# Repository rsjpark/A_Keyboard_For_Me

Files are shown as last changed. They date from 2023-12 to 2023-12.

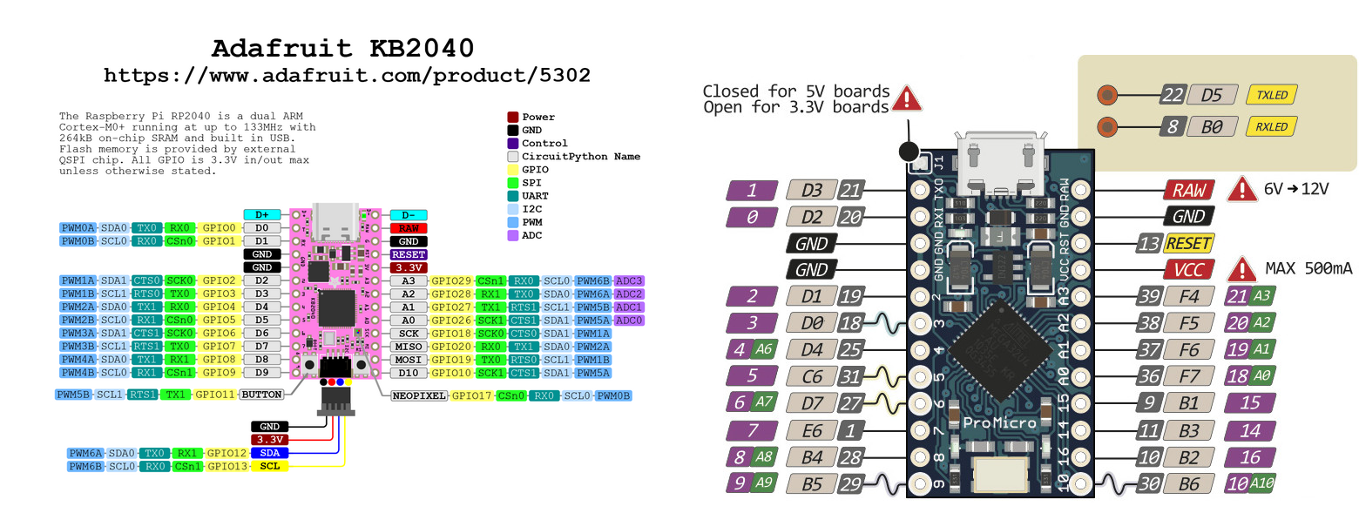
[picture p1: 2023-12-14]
slide images/0.2_pinout_comparison.png

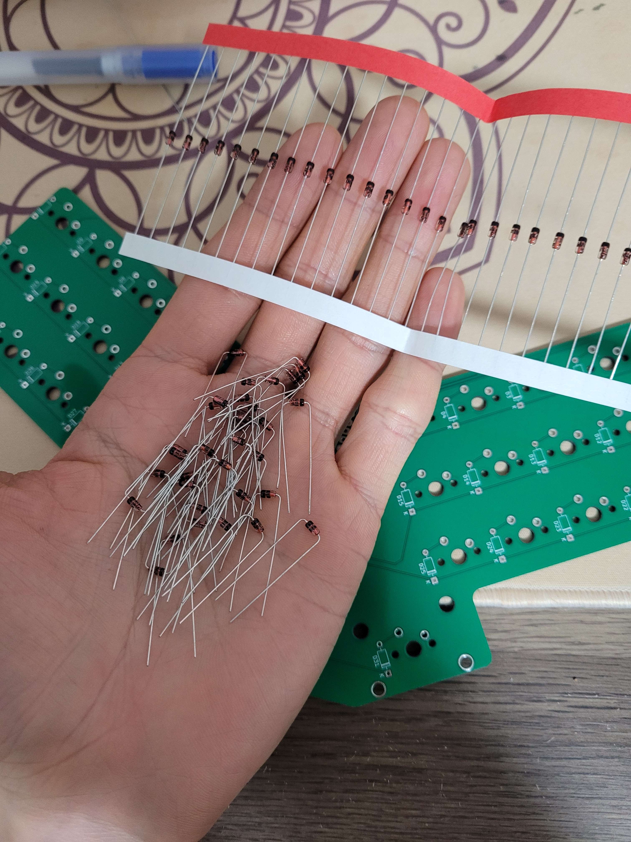
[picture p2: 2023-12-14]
slide images/007.jpg

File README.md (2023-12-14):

# A_Keyboard_For_Me
CISC 4900 RPark

# Goals
A Keyboard For Me was designed to create a common tool from the ground up to customize the ergonomics and to be a learning experience

# Process
What we can design and have manufactured ourselves reasonably are the case, pcb, and plate. Other miscellaneous parts will be bought or are already in possession.

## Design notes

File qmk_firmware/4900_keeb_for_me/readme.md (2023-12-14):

# A Keyboard For Me is a project designed to learn about the processes of making/designing a keyboard from the ground up in order to build a tool that is fully customized for me

# It allows me to tailor the shape of the keyboard for ergonomics as well as the firmware for workflow efficiency and ergonomics (having every key be near home row and not having to reach out more than 2 keys)

# I will tackle the challenges of designing/creating a case, pcb, plate, and firmware. Parts such as stabilizers, switches, keycaps, and other mechanical parts will be bought.

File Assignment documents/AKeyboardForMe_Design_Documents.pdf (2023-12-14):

A Keyboard For Me

Richard Park:
rsjpark2@gmail.com
richard.park24@bcmail.cuny.edu

The A Keyboard For Me aims to build a fully customized and functional keyboard from the ground up. It will begin by reexamining the archetypal keyboard to best fit my needs. It will look to first determine my personal preferences and then to build the case, pcb, plate, and firmware around that crucial factor. The hardware specifications will be determined by the ergonomic choices, and the firmware will be determined by my desired keymapping and preferred workflow.

Exact schedule is yet to be determined but I will be updating the trello often, and I plan on ordering manufacturing parts by mid/late October.

This is the todo trello board as of now, and they will be mapped to the schedule board later this week

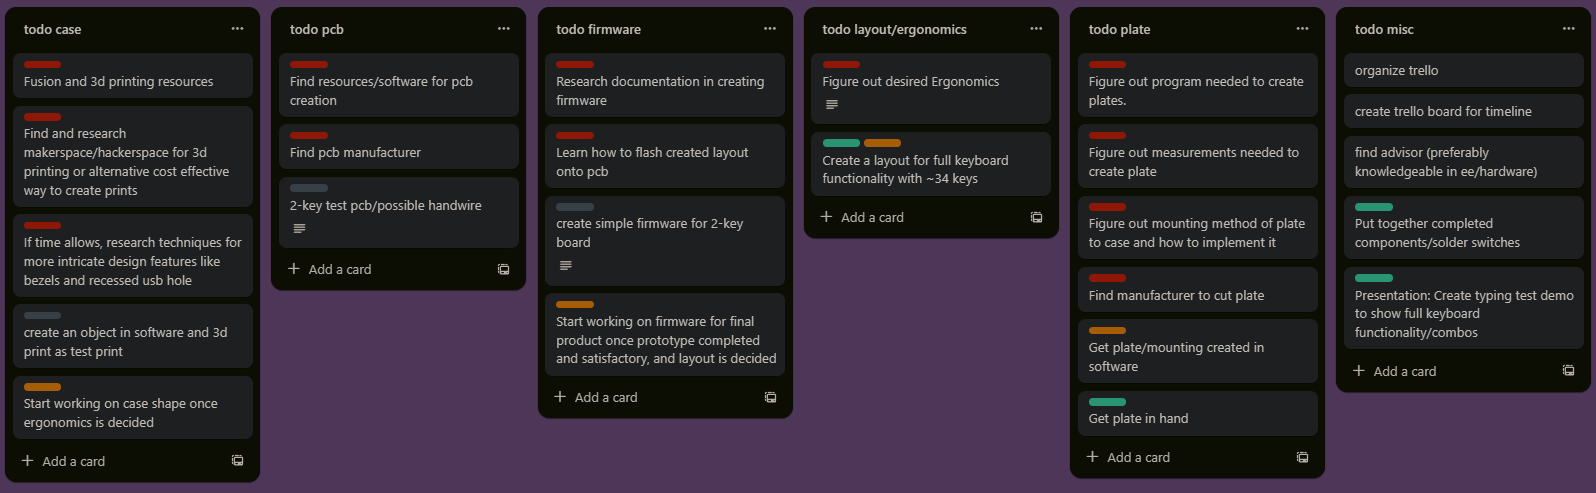
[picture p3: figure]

This opportunity to explore hardware and manufacturing offers me a stepping stone into further ventures for building tools/machines from the ground up. I would like to explore more with 3d printing and machining, working with circuit boards and electronics, and taking a deeper dive into programming and utilizing microcontrollers. This project offers a unique opportunity to explore all of those realms at once while also ending up with a fully tailored and functional end product.

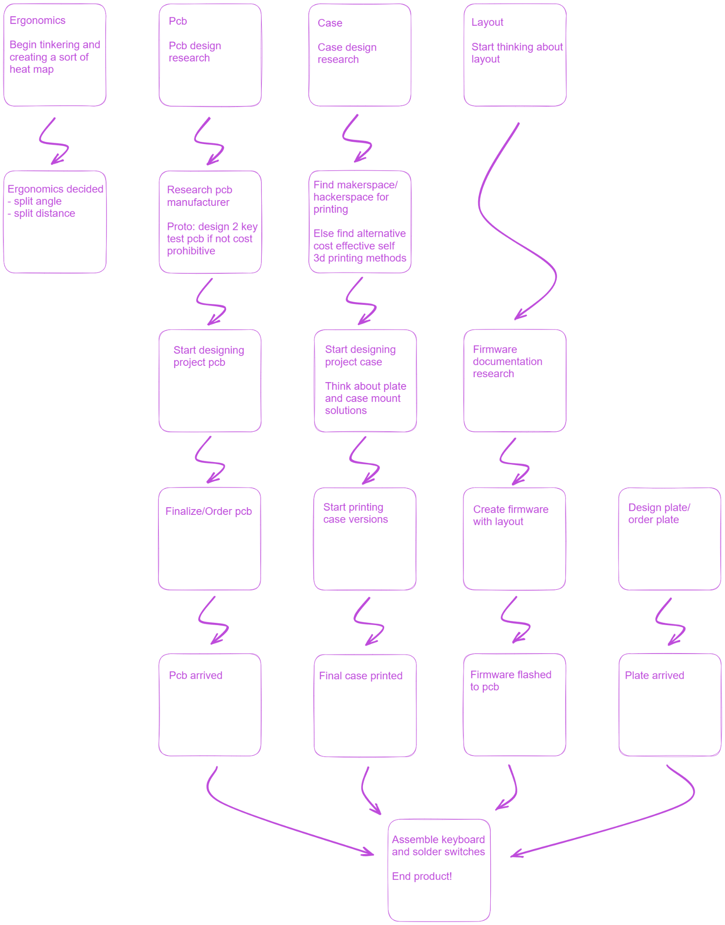
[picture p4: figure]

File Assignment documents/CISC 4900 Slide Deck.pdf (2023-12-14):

# A Keyboard For Me

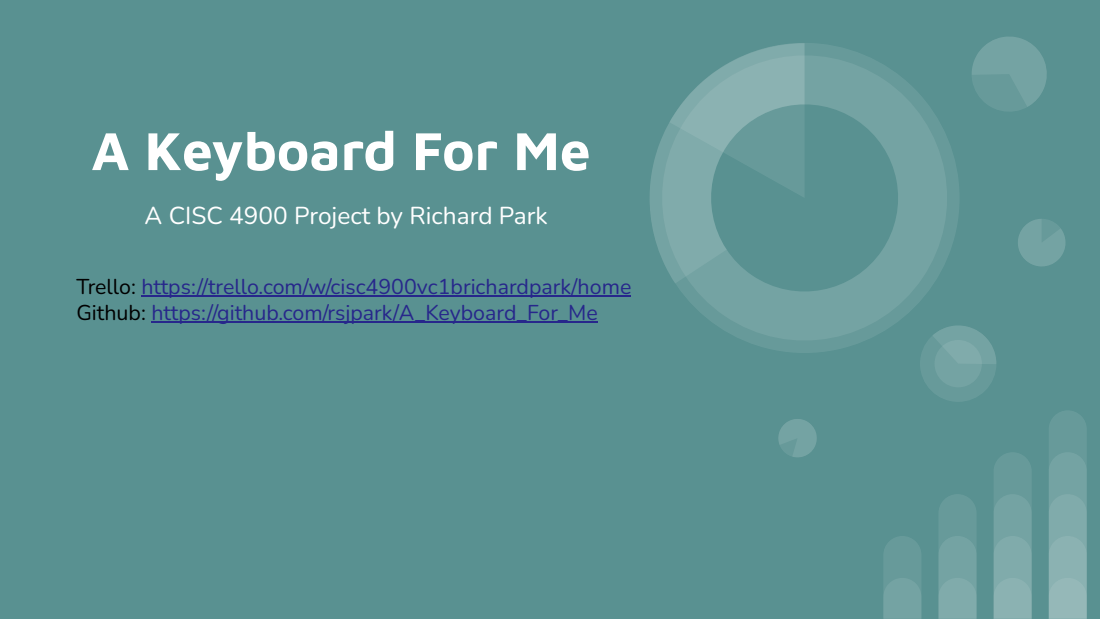
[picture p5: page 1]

A CISC 4900 Project by Richard Park

Trello: https://trello.com/w/cisc4900vc1brichardpark/home
Github: https://github.com/rsjpark/A_Keyboard_For_Me

# Case Design

Original Plans
- I had wanted to do a simple no frills case, that would be simple to print/manufacture and wouldn’t take up a bulk of my time.
Demo 1 Timeline
- Many of my hours were spent trying to get measurements for all of the aspects of the case, especially ones that I had not originally thought about.
- At the moment I have 4 case designs that I’m slightly iterating on, with 2 of them being one that I feel will make the final cut.
- I am still figuring out final decisions, as I hadn’t thought of specifics like, where the mounting holes should be since this case won’t be a single rectangle.
- I am hoping for a minimal amount of mounting holes so I will continue to iterate

# Case Design (cont.)

After Demo 1 Timeline

- After all of those designs, I had to scrap them due to pcb issues
- Having to accommodate the development board rather than just the mcu meant that I would have to change up dimensions

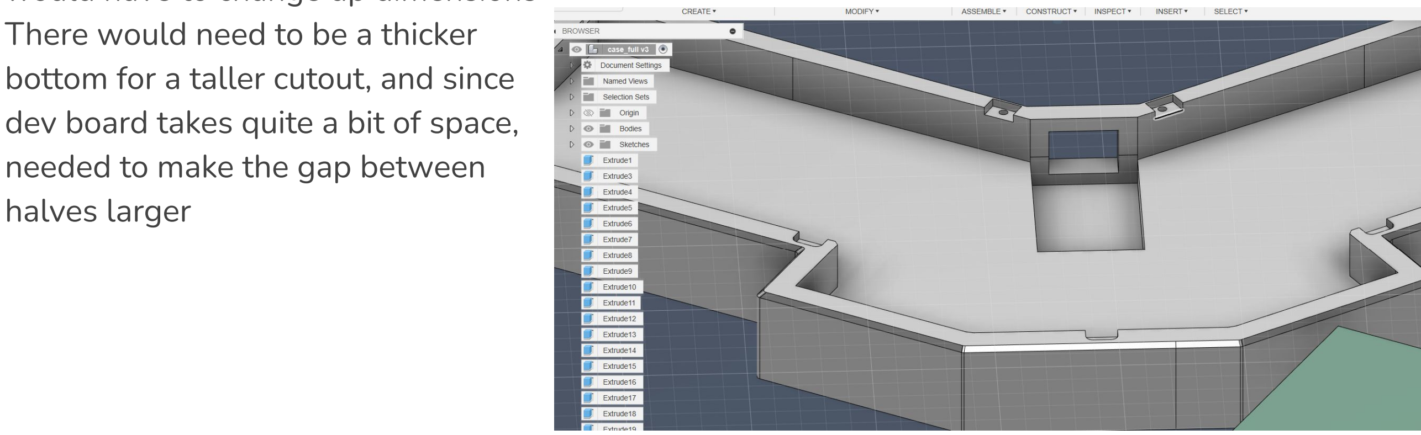
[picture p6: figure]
dev board takes quite a bit of space,; needed to make the gap between halves larger

- There would need to be a thicker
bottom for a taller cutout, and since | the

# Case Design (cont.)

After Demo 1 Timeline

- I decided to wait until my pcb was finalized and until I could get all of the dimensions (pcb, plate, development board, pin headers)
- This step took quite a while

# Case Design (cont.)

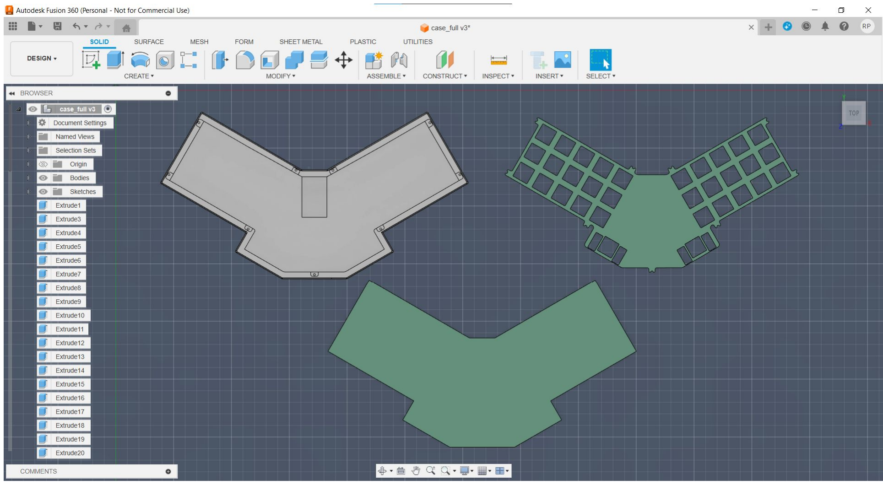
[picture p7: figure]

After Demo 1 Timeline

- The dimensions were given by creating an object in kicad that traced the dimensions of the plate and then imported as a step file into fusion
- After some hard fought tinkering the case came into its own

# Case Manufacturing

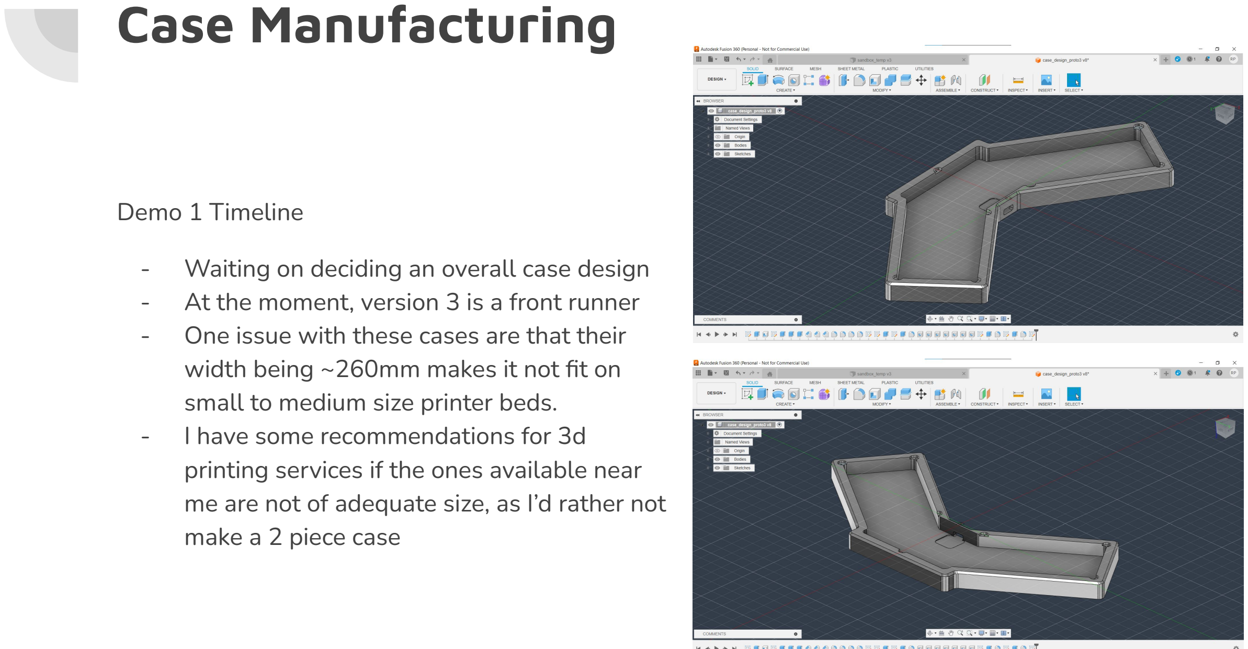
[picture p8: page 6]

Demo 1 Timeline

- Waiting on deciding an overall case design
- At the moment, version 3 is a front runner
- One issue with these cases are that their width being ~260mm makes it not fit on small to medium size printer beds.
- I have some recommendations for 3d printing services if the ones available near me are not of adequate size, as I’d rather not make a 2 piece case

# Case Manufacturing (cont.)

After Demo 1 Timeline

- I had originally planned to go to the Queens Library in Queensbridge to attempt to print the case, but was not able to due to availability.
- I chose to just make another order through jlc and sent in my files for printing
- Although I had created with tolerances in mind, the prints were very good, and made the 1mm edge tolerance I measured with look like the Grand Canyon when the plate was screwed in

# Case Manufacturing (cont.)

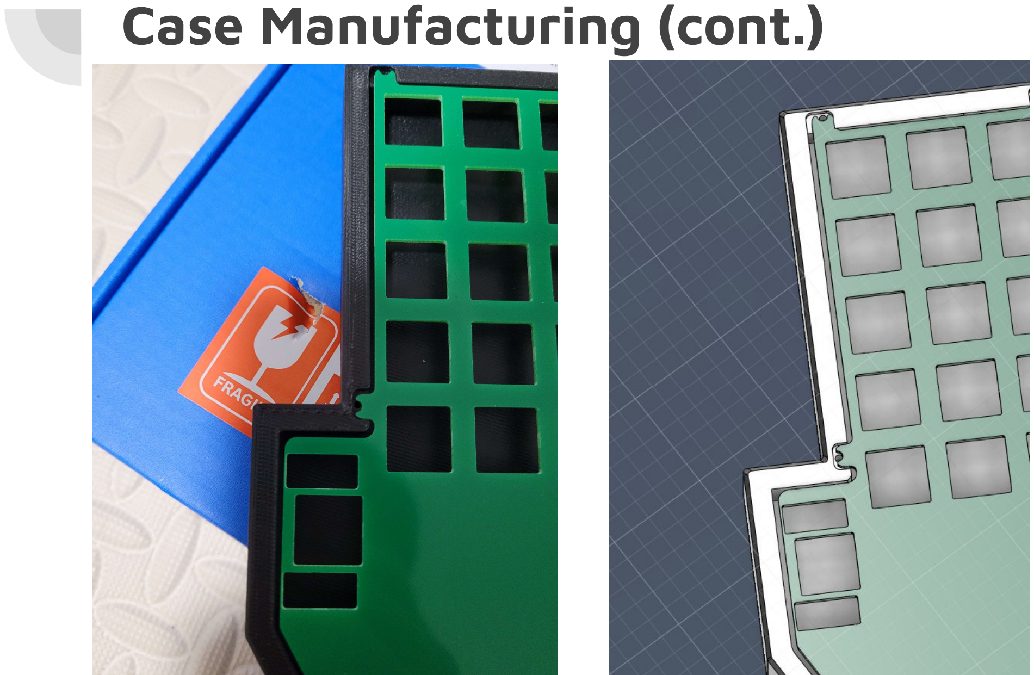
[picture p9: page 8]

# PCB Design

Original Plans

- Create an integrated pcb (simple as that)

Demo 1 Timeline

- As presented in the demo, I had finished up the pcb with rp2040/kb2040 devboard.
- As I wait on production, I am working on a whole new revision that is an integrated pcb

# PCB Design (cont.)

After Demo 1 Timeline
- My original plan was to go and order the pcb I had by Demo 1 as the safety/working exercise pcb.
- …I couldn’t send it in for production. It was too messy
- I decided to just start working on the integrated pcb and have that ordered within a few weeks.
- It turned out to be too hard of a task. I was reading documentation on all of the extra parts needed that was already included in the development board.
- I was working on learning up on crystals/oscillators that were necessary due to the usb’s strict protocols on timing, but realized I was running out of time.

# PCB Design (cont.)

After Demo 1 Timeline

- I decided that with the new stuff that I learned along the way, I needed to get the kb2040 pcb redone and out for production.
- This still took around 2 weeks as I was still having troubles with routing and trying to troubleshoot the errors showing up in the drc
- Eventually with trial and error of redefining the pins on the dev board I was able to get it to a place where I could send it in for production

# PCB Design (cont.)

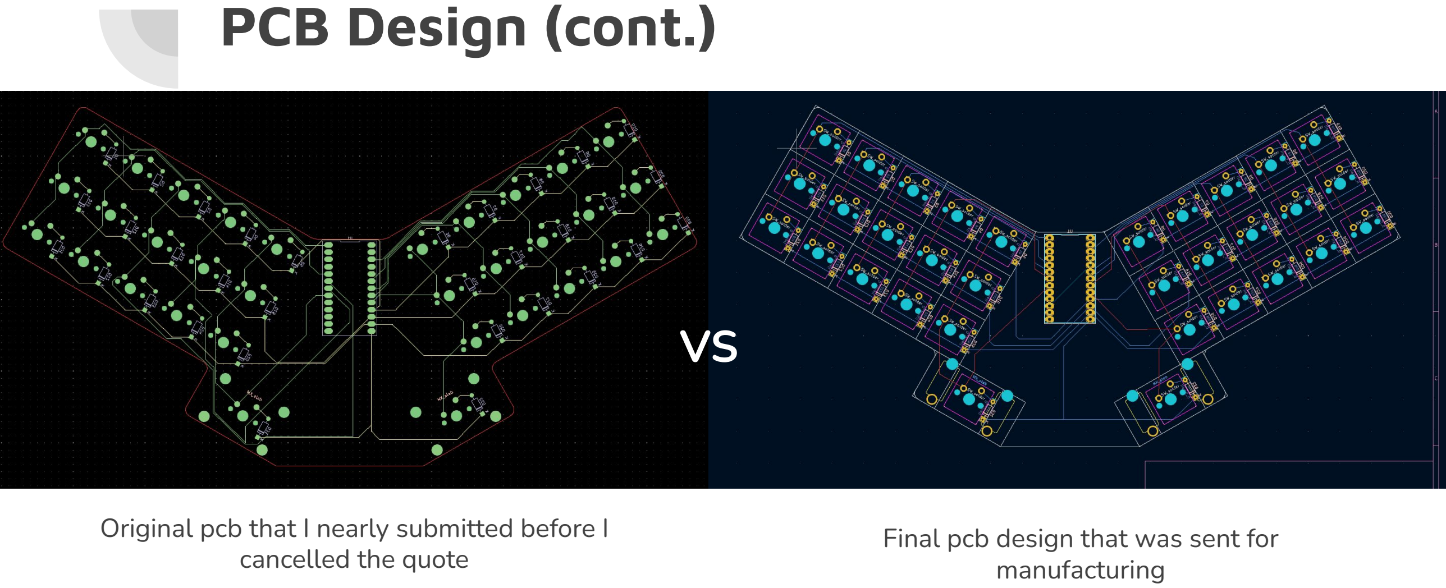
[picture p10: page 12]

VS

Original pcb that I nearly submitted before I cancelled the quote

Final pcb design that was sent for manufacturing

# PCB Manufacturing

Demo 1 Timeline

- Currently I have the devkit version of the pcb going through a manual quote because the autoquoter was having issues. I hope to hear back from them in a few days.
- While that pcb is being quoted and sent for production, I will be continuing on working on the integrated pcb, making the devkit pcb a backup in case something goes wrong or I don’t have enough time.
- Side note for the case, I saw that jlc has 3d printing and material milling services as well, so if all goes well and the price is reasonable I might check out their options.
- Milled polycarbonate or abs seems like a very interesting option

# PCB Manufacturing (cont.)

After Demo 1 Timeline
- The ordering process came with its own hiccups.
- Many of the scripts that were used to create a BOM and the centroid

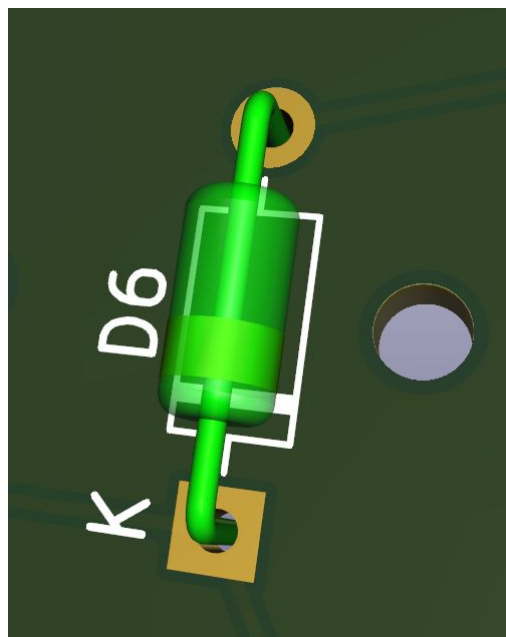
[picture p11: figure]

files for jlc were not working and it took a bit of work to troubleshoot the errors
- Those files were eventually created and sent for quoting, and in | a
few days I received a notice from jlc that there was an issue with
my order in which I had chosen parts (surface mount diode) that | did
not work with the footprint that I had placed on my pcb
(through holes for tht diodes)...

# PCB Manufacturing (cont.)

After Demo 1 Timeline

- After some back and forth emails, I had decided that it would be easier to order and solder the diodes myself, rather than replace the footprints due to the rotation/positioning of my footprints
- They cancelled the assembly and proceeded with the order (which also had the plate in it)
- After receiving the parts in hand, everything looked great, which was a relief since their integrated gerber viewer was showing some wonky things

# PCB Manufacturing (cont.)

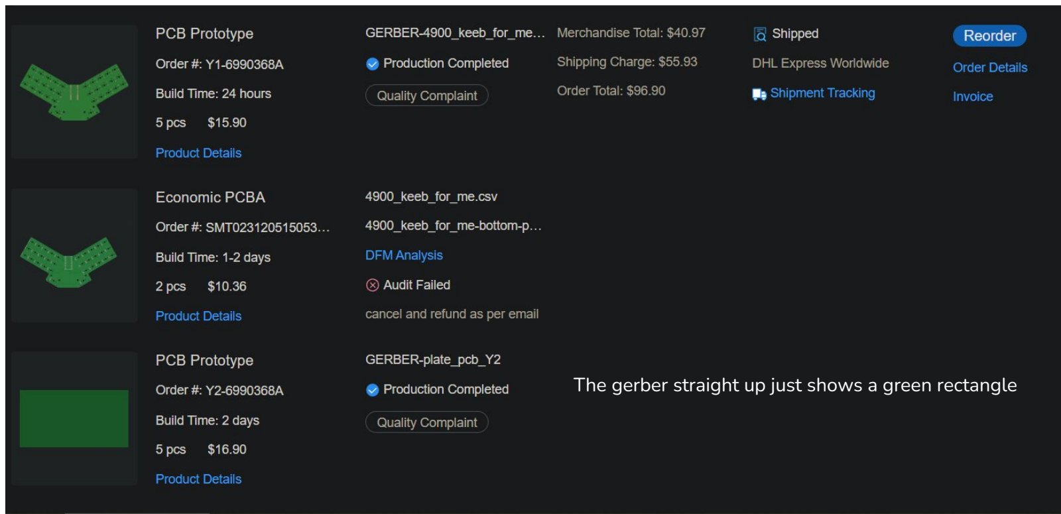
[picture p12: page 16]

The gerber straight up just shows a green rectangle

# Plate Design

Original Plans

- Create plates based off of pcb and case designs
- Create them while waiting for pcb manufacturing and case prototyping

Demo 1 Timeline

- Not much has changed
- Design follows the case design, so once the mounting worries are sorted out, should be easy enough to create a plate

# Plate Design (cont.)

After Demo 1 Timeline

- The plate design portion was rather simple, and just took a few hours of playing around with the pcb kicad files and some lines/filleting
- I was able to use the dimensions of the plate to base my case dimensions off of as mentioned before

# Plate Design (cont.)

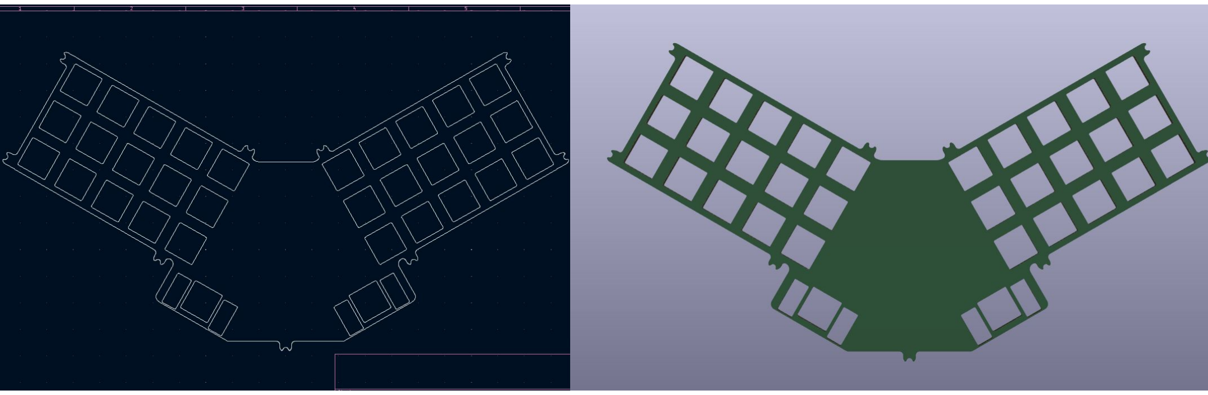
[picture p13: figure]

# Plate Manufacturing

Demo 1 Timeline

- Waiting on final case design
- Still the same plans as talked about in the demo

# Plate Manufacturing (cont.)

After Demo 1 Timeline

- Sent in files for manufacturing along with pcb
- Nothing went wrong in this department

# Plate Manufacturing (cont.)

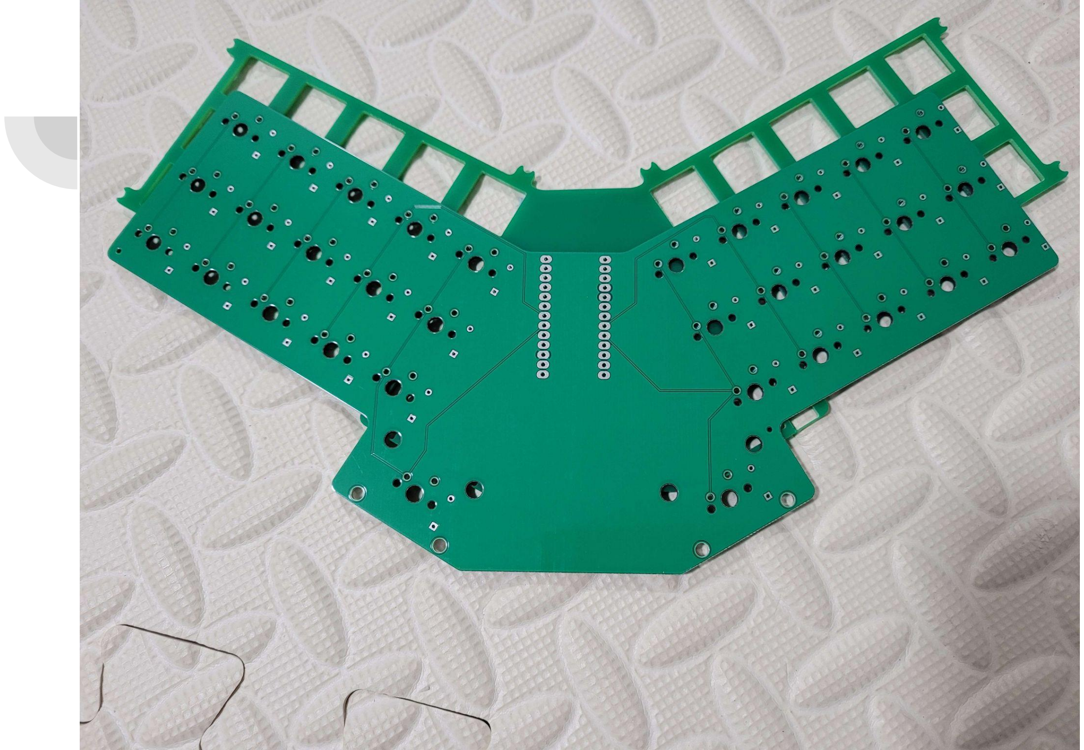
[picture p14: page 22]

# Layout Creation

Demo 1 Timeline

- Layout has been finalized
- Layers have been organized in google sheets so that it won’t be a headache when creating a firmware for it

# Firmware creation

Demo 1 Timeline

- Have not started working on firmware

# Firmware creation (cont.)

After Demo 1 Timeline
- Firmware creation was pretty straightforward
- Reading the QMK documentation and looking at examples of other qmk keyboard firmwares made it pretty clear what I needed/wanted
- After I implemented my layout I had some errors in compiling my firmware with qmk msys and chalked it up to some mistakes and decided to chip at it over time.
- After some time I realized that nothing I was trying was working, and after some research and asking around I realized that in order to create your own keyboard/firmware and get it compiled in qmk you need to submit a pull request towards the main branch and get it accepted

# Firmware creation (cont.)

After Demo 1 Timeline

- This was an issue as I thought that the firmware side of things was pretty much nearly done
- I did more digging and found 2 possible solutions.
- Compile the firmware with the pico-sdk rather than qmk
- Try out a hack where you use an already accepted keyboard’s files and insert your own and try to compile it
- At this point I didn’t have enough time to learn building firmware that wasn’t from QMK, and my jlc orders were still not in hand
- I decided to go through the list of keyboards in the list until I found a keyboard that was similar to mine and decided insert my files and compile my firmware as if it was that keyboard
- I chose the reviung39 because it looked similar to my board, but it turned out that they were created very differently.
- There was quite a bit of troubleshooting that took a few weeks, but I eventually was able to compile my firmware and got the uf2 file that I needed to flash my rp2040/kb2040

# Assembly

- This was when I started testing my board since I had put the firmware into the kb2040 already in advance.
- It was not pretty. The keytester was showing up random keys and mostly no keypresses.
- After some troubleshooting I decided to just solder in the switches and try to get a complete look of the build.
- The screws threaded themselves well and at least the physical build was complete. Although I am looking to sand the usb port down a few mm
- I took out the pcb from the case and have been troubleshooting since.
- I was able to get to this point where many of the keys are still not registering correctly.
- I am trying to work until the very end, but cannot determine where the issues lie. I’m wondering if it’s a combination of both issues in the firmware and hardware/assembly.

# Assembly

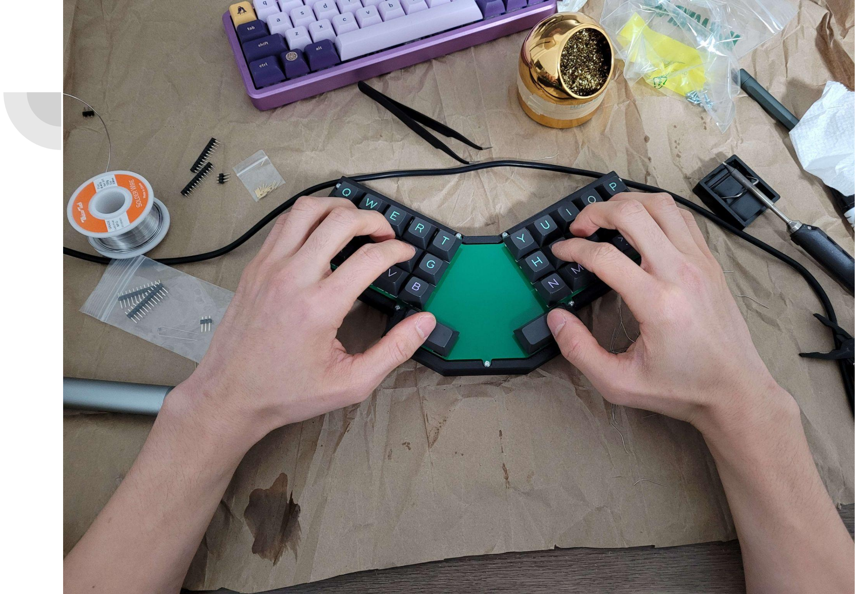
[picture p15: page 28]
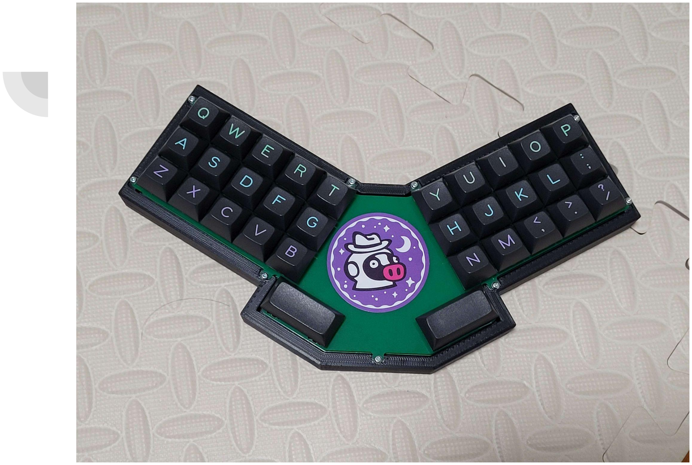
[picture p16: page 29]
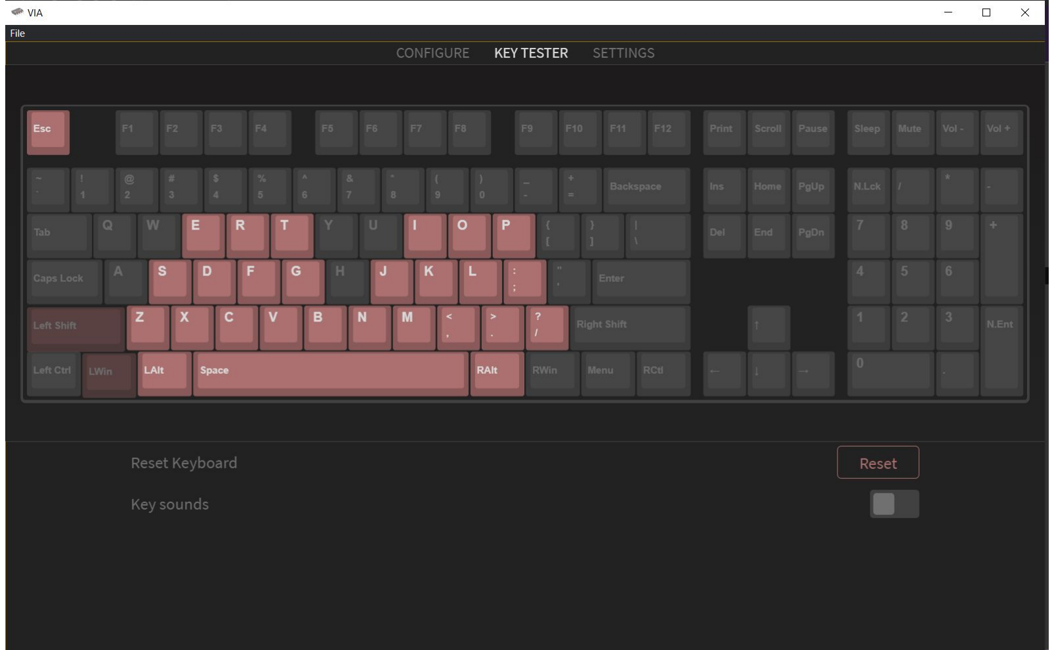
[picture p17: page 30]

# Final Thoughts

- In the end I do not have a fully functional working product
- I feel like I’m very close and will continue working this out until I have a fully functional build,
- This project was a great experience in all of the issues that could arise when I create my next design.
- I think finishing this out will give me even better insight that I can carry along with me.
- Although this was very stressful (lol) I am very happy to have dove into the deep end to get me rolling on electrical components and 3d modeling.
- I retrospect, I think treating this project as both a learning/getting experience, as well as trying to fulfill a goal of satisfying my ergonomic needs was way too much.
- I believe starting out with a smaller perhaps 4-key test board, finalizing it, then moving onto a slightly more complicated, but still normal board would have really made things fall better into schedule.

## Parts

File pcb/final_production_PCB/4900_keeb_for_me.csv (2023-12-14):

Comment | Designator | Footprint | LCSC Part #
1N4148 | D1,D2,D3,D4,D5,D6,D7,D8,D9,D10,D11,D12,D13,D14,D15,D16,D17,D18,D19,D20,D21,D22,D23,D24,D25,D26,D27,D28,D29,D30,D31,D32,U1 | Diode_THT:D_DO-35_SOD27_P7.62mm_Horizontal

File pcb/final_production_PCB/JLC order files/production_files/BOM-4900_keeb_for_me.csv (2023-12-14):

Comment | Designator | Footprint | LCSC
MX_SW_solder | SW3 | SW_MX_1u
MX_SW_solder | SW21 | SW_MX_1u
MX_SW_solder | SW22 | SW_MX_1u
MX_SW_solder | SW17 | SW_MX_1u
MX_SW_solder | SW27 | SW_MX_1u
MX_SW_solder | SW15 | SW_MX_1u
MX_SW_solder | SW29 | SW_MX_1u
MX_SW_solder | SW1 | SW_MX_1u
MX_SW_solder | SW12 | SW_MX_1u
MX_SW_solder | SW13 | SW_MX_1u
MX_SW_solder | SW6 | SW_MX_1u
MX_SW_solder | SW28 | SW_MX_1u
MX_SW_solder | SW9 | SW_MX_1u
MX_SW_solder | SW19 | SW_MX_1u
MX_SW_solder | SW20 | SW_MX_1u
MX_stab | S32 | STAB_MX_P_2u
MX_SW_solder | SW31 | SW_MX_1u
MX_SW_solder | SW7 | SW_MX_1u
MX_SW_solder | SW4 | SW_MX_1u
MX_SW_solder | SW5 | SW_MX_1u
MX_SW_solder | SW18 | SW_MX_1u
MX_SW_solder | SW11 | SW_MX_1u
MX_SW_solder | SW2 | SW_MX_1u
MX_SW_solder | SW23 | SW_MX_1u
MX_SW_solder | SW14 | SW_MX_1u
MX_SW_solder | SW24 | SW_MX_1u
MX_stab | S31 | STAB_MX_P_2u
MX_SW_solder | SW25 | SW_MX_1u
MX_SW_solder | SW8 | SW_MX_1u
MX_SW_solder | SW16 | SW_MX_1u
MX_SW_solder | SW32 | SW_MX_1u
MX_SW_solder | SW10 | SW_MX_1u
MX_SW_solder | SW30 | SW_MX_1u
MX_SW_solder | SW26 | SW_MX_1u
D_Small | D21 | D_DO-35_SOD27_P7.62mm_Horizontal
D_Small | D16 | D_DO-35_SOD27_P7.62mm_Horizontal
D_Small | D7 | D_DO-35_SOD27_P7.62mm_Horizontal
D_Small | D11 | D_DO-35_SOD27_P7.62mm_Horizontal
D_Small | D15 | D_DO-35_SOD27_P7.62mm_Horizontal
D_Small | D18 | D_DO-35_SOD27_P7.62mm_Horizontal
D_Small | D17 | D_DO-35_SOD27_P7.62mm_Horizontal
D_Small | D28 | D_DO-35_SOD27_P7.62mm_Horizontal
D_Small | D2 | D_DO-35_SOD27_P7.62mm_Horizontal
D_Small | D1 | D_DO-35_SOD27_P7.62mm_Horizontal
D_Small | D25 | D_DO-35_SOD27_P7.62mm_Horizontal
D_Small | D19 | D_DO-35_SOD27_P7.62mm_Horizontal
D_Small | D24 | D_DO-35_SOD27_P7.62mm_Horizontal
D_Small | D31 | D_DO-35_SOD27_P7.62mm_Horizontal
D_Small | D22 | D_DO-35_SOD27_P7.62mm_Horizontal
D_Small | D30 | D_DO-35_SOD27_P7.62mm_Horizontal
D_Small | D29 | D_DO-35_SOD27_P7.62mm_Horizontal
D_Small | D3 | D_DO-35_SOD27_P7.62mm_Horizontal
~ | U1 | Pro-Micro
D_Small | D5 | D_DO-35_SOD27_P7.62mm_Horizontal
D_Small | D27 | D_DO-35_SOD27_P7.62mm_Horizontal
D_Small | D13 | D_DO-35_SOD27_P7.62mm_Horizontal
D_Small | D23 | D_DO-35_SOD27_P7.62mm_Horizontal
D_Small | D26 | D_DO-35_SOD27_P7.62mm_Horizontal
D_Small | D20 | D_DO-35_SOD27_P7.62mm_Horizontal
D_Small | D14 | D_DO-35_SOD27_P7.62mm_Horizontal
D_Small | D8 | D_DO-35_SOD27_P7.62mm_Horizontal
D_Small | D6 | D_DO-35_SOD27_P7.62mm_Horizontal
D_Small | D10 | D_DO-35_SOD27_P7.62mm_Horizontal
D_Small | D4 | D_DO-35_SOD27_P7.62mm_Horizontal
D_Small | D32 | D_DO-35_SOD27_P7.62mm_Horizontal
D_Small | D9 | D_DO-35_SOD27_P7.62mm_Horizontal
D_Small | D12 | D_DO-35_SOD27_P7.62mm_Horizontal

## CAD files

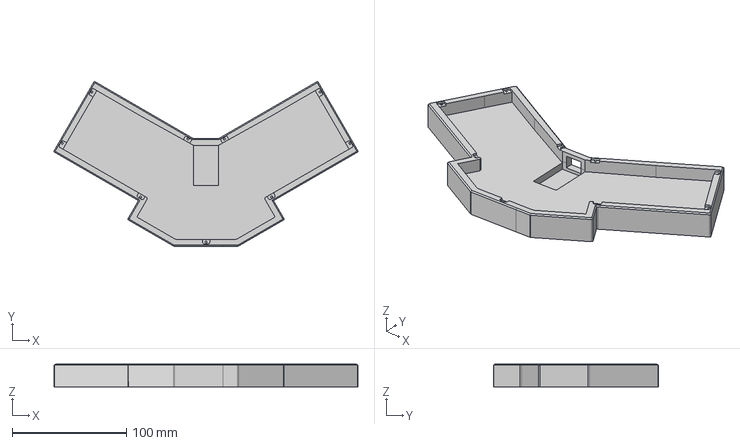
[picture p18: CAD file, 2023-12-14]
case/case_full v3.step
265.9 x 144.1 x 20.0 mm

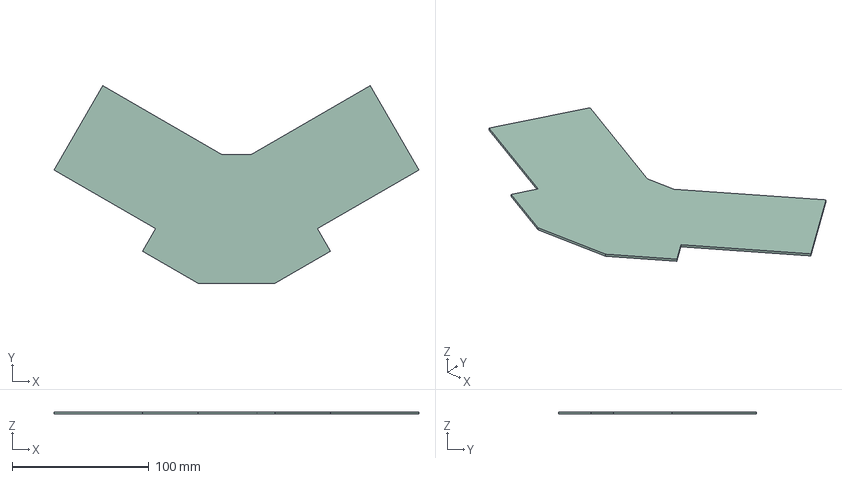
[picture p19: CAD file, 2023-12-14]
case/case_outline.step
266.7 x 144.5 x 1.60 mm

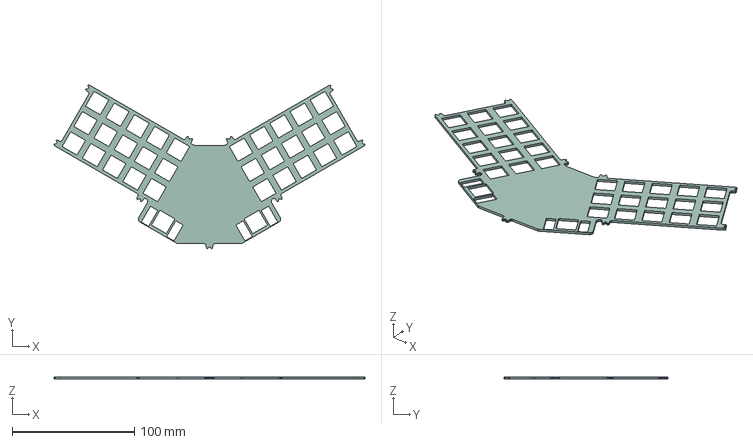
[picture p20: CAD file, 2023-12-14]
case/plate_pcb v1.step
254.0 x 133.7 x 1.60 mm

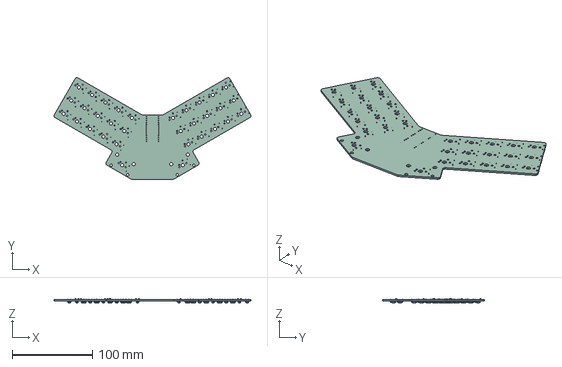
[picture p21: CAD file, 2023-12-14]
case/fixed_pcb.step
245.8 x 127.0 x 5.01 mm
_autosave-4900_keeb_for_me PCB

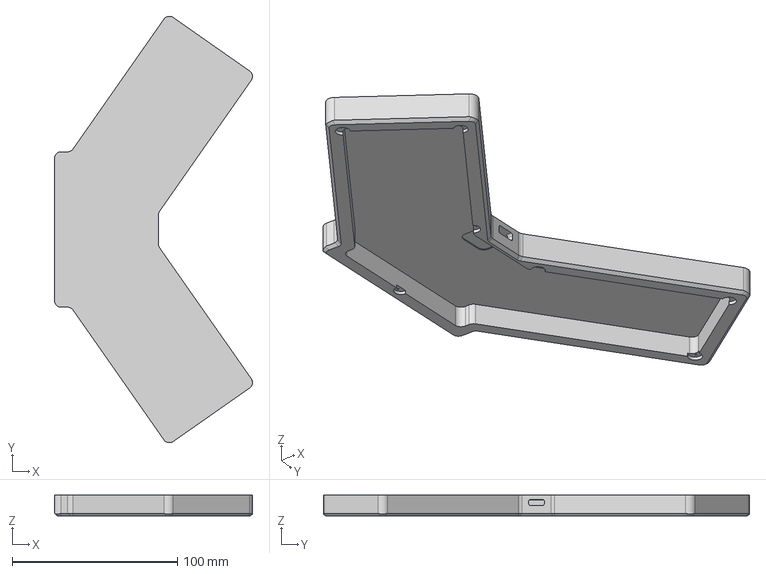
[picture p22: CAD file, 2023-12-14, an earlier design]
case/case_4900_outdated.step
119.8 x 258.0 x 12.5 mm

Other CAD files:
case/fusion_360_crash_course_examples/fillet_chamfer_exercise.f3d
case/fusion_360_crash_course_examples/phone_stand.f3d

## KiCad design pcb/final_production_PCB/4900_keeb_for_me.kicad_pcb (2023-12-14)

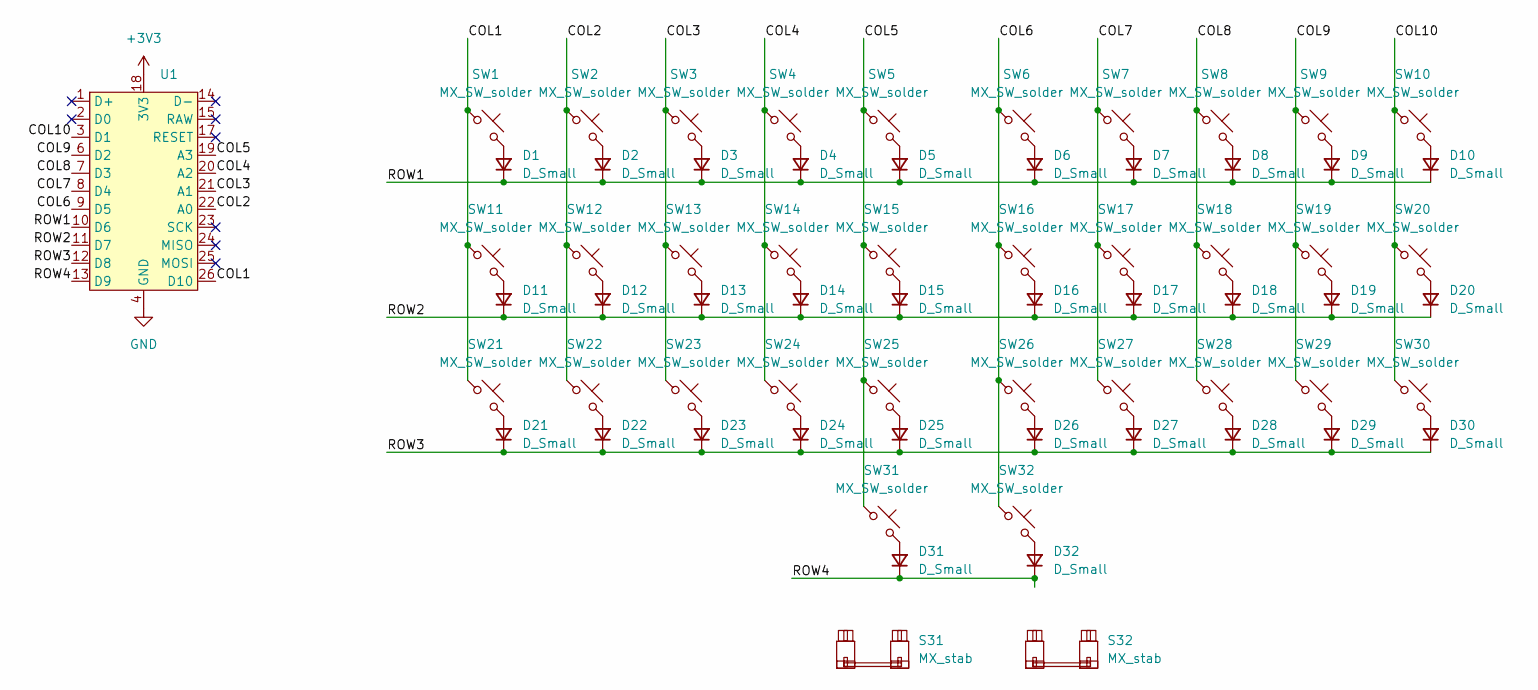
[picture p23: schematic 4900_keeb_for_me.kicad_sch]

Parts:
D1, D2, D3, D4, D5, D6, D7, D8, D9, D10, D11, D12, D13, D14, D15, D16, D17, D18, D19, D20, D21, D22, D23, D24, D25, D26, D27, D28, D29, D30, D31, D32: D_Small; D_DO-35_SOD27_P7.62mm_Horizontal
S31, S32: MX_stab; STAB_MX_P_2u
SW1, SW2, SW3, SW4, SW5, SW6, SW7, SW8, SW9, SW10, SW11, SW12, SW13, SW14, SW15, SW16, SW17, SW18, SW19, SW20, SW21, SW22, SW23, SW24, SW25, SW26, SW27, SW28, SW29, SW30, SW31, SW32: MX_SW_solder; SW_MX_1u
U1: Pro-Micro

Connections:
+3V3: U1.18 (3V3)
/COL1: SW1.1, SW11.1, SW21.1, U1.26 (D10)
/COL2: SW2.1, SW12.1, SW22.1, U1.22 (A0)
/COL3: SW3.1, SW13.1, SW23.1, U1.21 (A1)
/COL4: SW4.1, SW14.1, SW24.1, U1.20 (A2)
/COL5: SW5.1, SW15.1, SW25.1, SW31.1, U1.19 (A3)
/COL6: SW6.1, SW16.1, SW26.1, SW32.1, U1.9 (D5)
/COL7: SW7.1, SW17.1, SW27.1, U1.8 (D4)
/COL8: SW8.1, SW18.1, SW28.1, U1.7 (D3)
/COL9: SW9.1, SW19.1, SW29.1, U1.6 (D2)
/COL10: SW10.1, SW20.1, SW30.1, U1.3 (D1)
/ROW1: D1.1 (K), D2.1 (K), D3.1 (K), D4.1 (K), D5.1 (K), D6.1 (K), D7.1 (K), D8.1 (K), D9.1 (K), D10.1 (K), U1.10 (D6)
/ROW2: D11.1 (K), D12.1 (K), D13.1 (K), D14.1 (K), D15.1 (K), D16.1 (K), D17.1 (K), D18.1 (K), D19.1 (K), D20.1 (K), U1.11 (D7)
/ROW3: D21.1 (K), D22.1 (K), D23.1 (K), D24.1 (K), D25.1 (K), D26.1 (K), D27.1 (K), D28.1 (K), D29.1 (K), D30.1 (K), U1.12 (D8)
/ROW4: D31.1 (K), D32.1 (K), U1.13 (D9)
GND: U1.4 (GND), U1.5 (GND), U1.16 (GND)
unnamed: D1.2 (A), SW1.2
unnamed: D2.2 (A), SW2.2
unnamed: D3.2 (A), SW3.2
unnamed: D4.2 (A), SW4.2
unnamed: D5.2 (A), SW5.2
unnamed: D6.2 (A), SW6.2
unnamed: D7.2 (A), SW7.2
unnamed: D8.2 (A), SW8.2
unnamed: D9.2 (A), SW9.2
unnamed: D10.2 (A), SW10.2
unnamed: D11.2 (A), SW11.2
unnamed: D12.2 (A), SW12.2
unnamed: D13.2 (A), SW13.2
unnamed: D14.2 (A), SW14.2
unnamed: D15.2 (A), SW15.2
unnamed: D16.2 (A), SW16.2
unnamed: D17.2 (A), SW17.2
unnamed: D18.2 (A), SW18.2
unnamed: D19.2 (A), SW19.2
unnamed: D20.2 (A), SW20.2
unnamed: D21.2 (A), SW21.2
unnamed: D22.2 (A), SW22.2
unnamed: D23.2 (A), SW23.2
unnamed: D24.2 (A), SW24.2
unnamed: D25.2 (A), SW25.2
unnamed: D26.2 (A), SW26.2
unnamed: D27.2 (A), SW27.2
unnamed: D28.2 (A), SW28.2
unnamed: D29.2 (A), SW29.2
unnamed: D30.2 (A), SW30.2
unnamed: D31.2 (A), SW31.2
unnamed: D32.2 (A), SW32.2

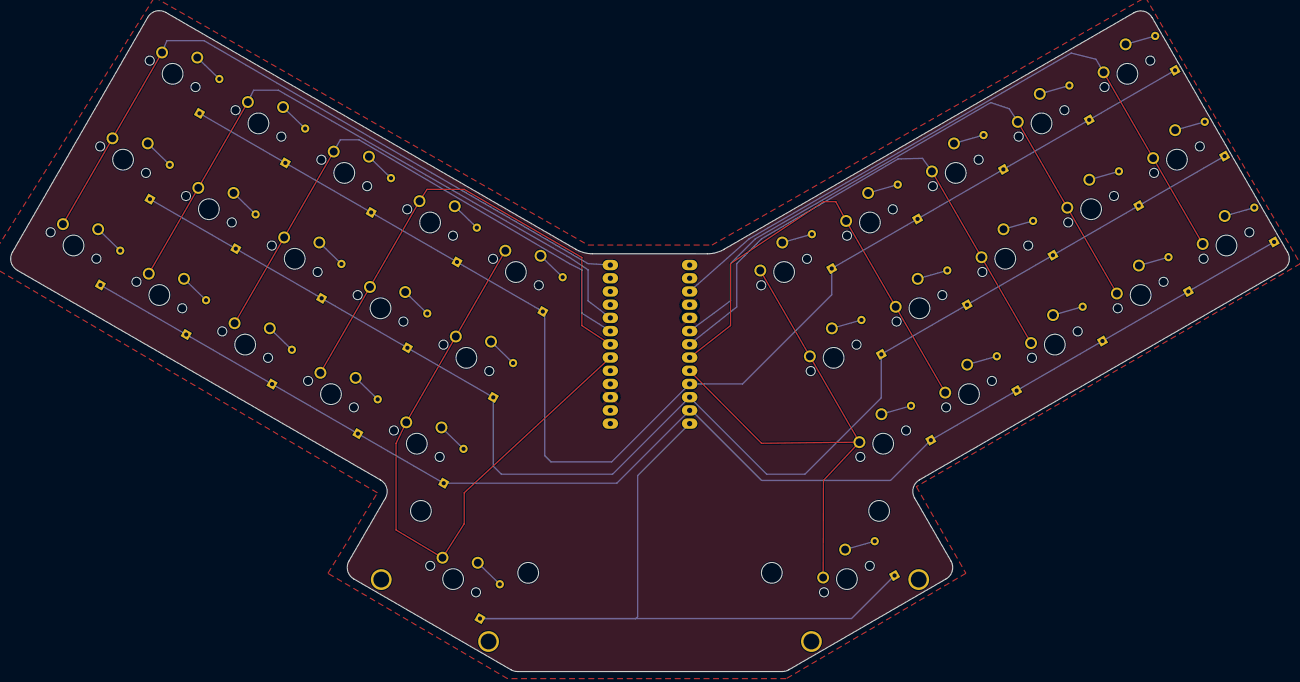
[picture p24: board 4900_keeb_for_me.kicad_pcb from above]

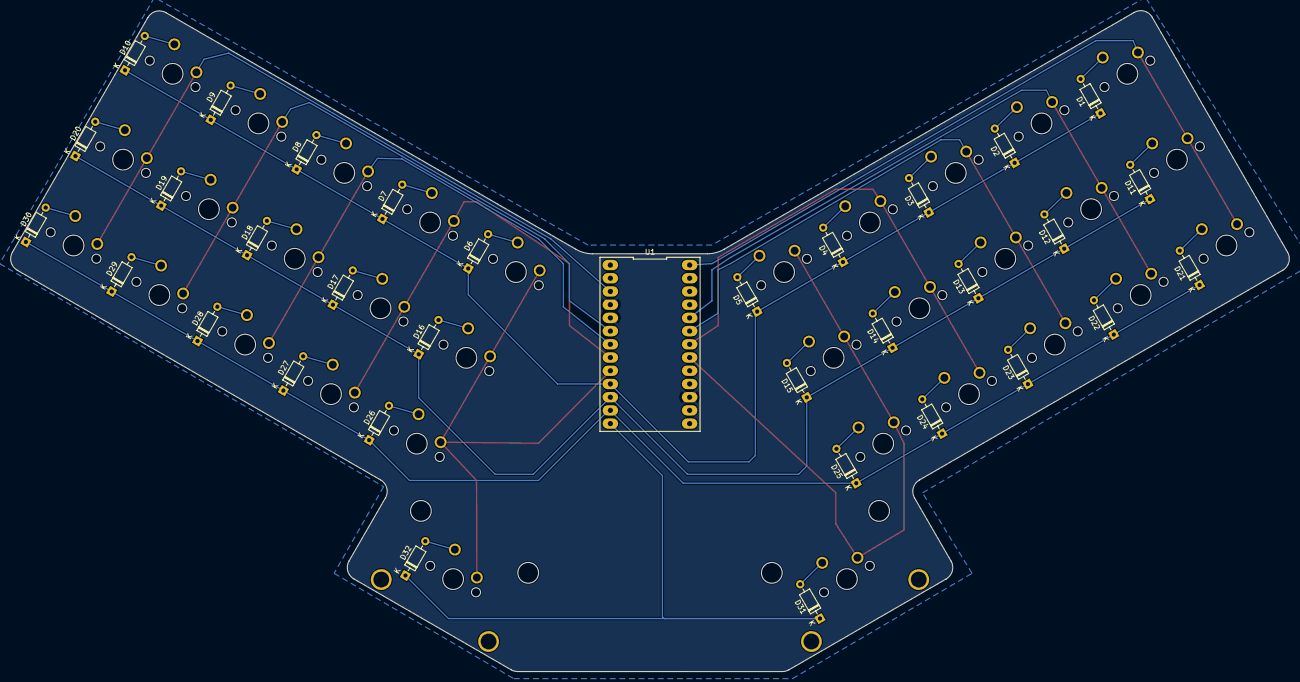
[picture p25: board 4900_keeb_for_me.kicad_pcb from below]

Board: 2 copper layers, 245.8 x 127.0 mm, 67 parts (33 on the bottom side), 47 nets.

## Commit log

2023-12-14 fusion exercise files, various .steps used for measuring, final case .step
    [case_4900_outdated.step, case_full v3.step, case_outline.step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]
2023-12-14 an example of the horrible routing, and the production pcb
    [4900_keeb_for_me-CuBottom.gbr, 4900_keeb_for_me-CuTop.gbr, 4900_keeb_for_me-EdgeCuts.gbr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]
2023-12-14 plate files
    [BOM-plate_pcb.csv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]
